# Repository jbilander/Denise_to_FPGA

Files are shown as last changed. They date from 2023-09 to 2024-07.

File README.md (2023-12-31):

# Denise_to_FPGA
A small adapter-board that connects 12-bit RGB, 14 MHz CLK, PIXELSW and SYNC-signals on Denise to a FPGA-board via a 5V-tolerant buffer.
A synchronous 14 MHz clock is generated from `C7M XOR CDAC` by using a `74LVC1G86`-chip. This will be fed into the FPGA's PLL.

Board is two layers.

WORK IN PROGRESS, NOT FULLY TESTED YET!

***

<a href="images/Denise_to_FPGA_pic1.png">
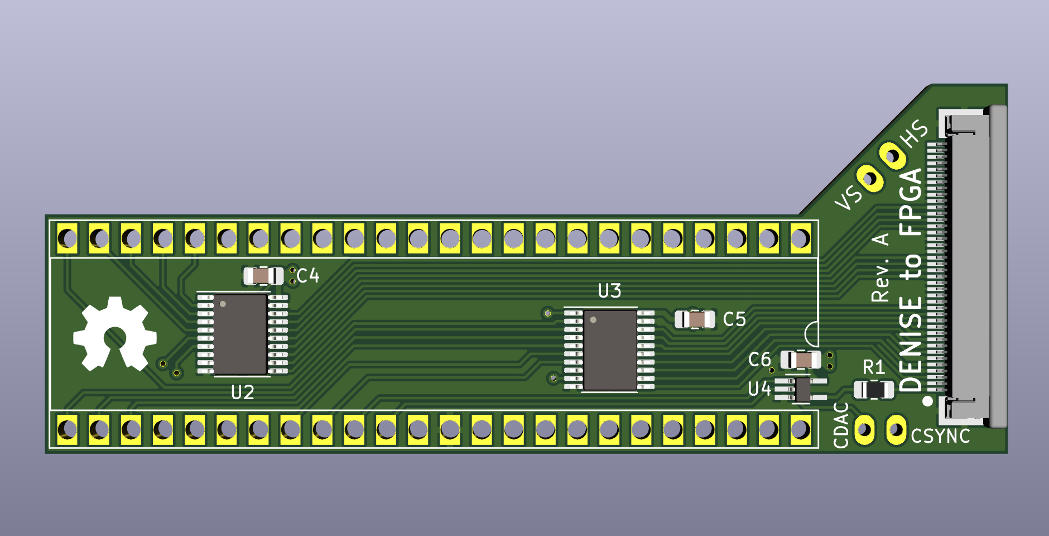
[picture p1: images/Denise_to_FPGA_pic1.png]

</a>
<a href="images/Denise_to_FPGA_pic2.png">
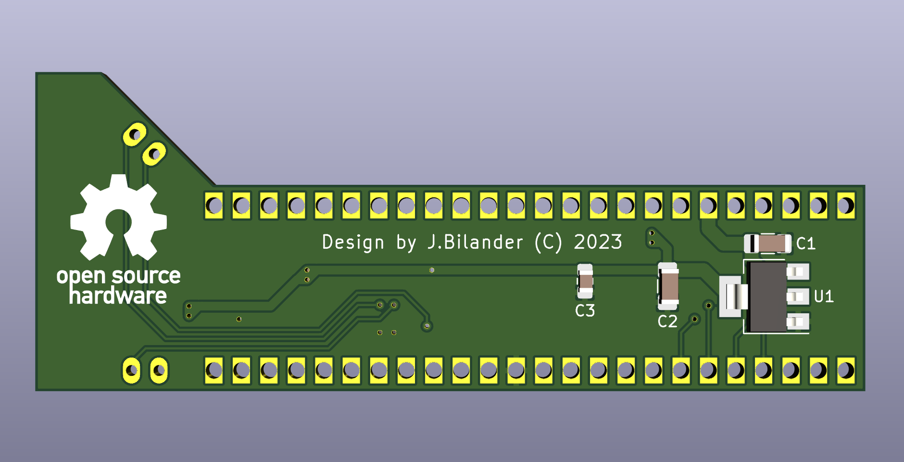
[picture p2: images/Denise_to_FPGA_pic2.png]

</a>

***
<a href="images/Denise_to_FPGA_pic3.jpg">
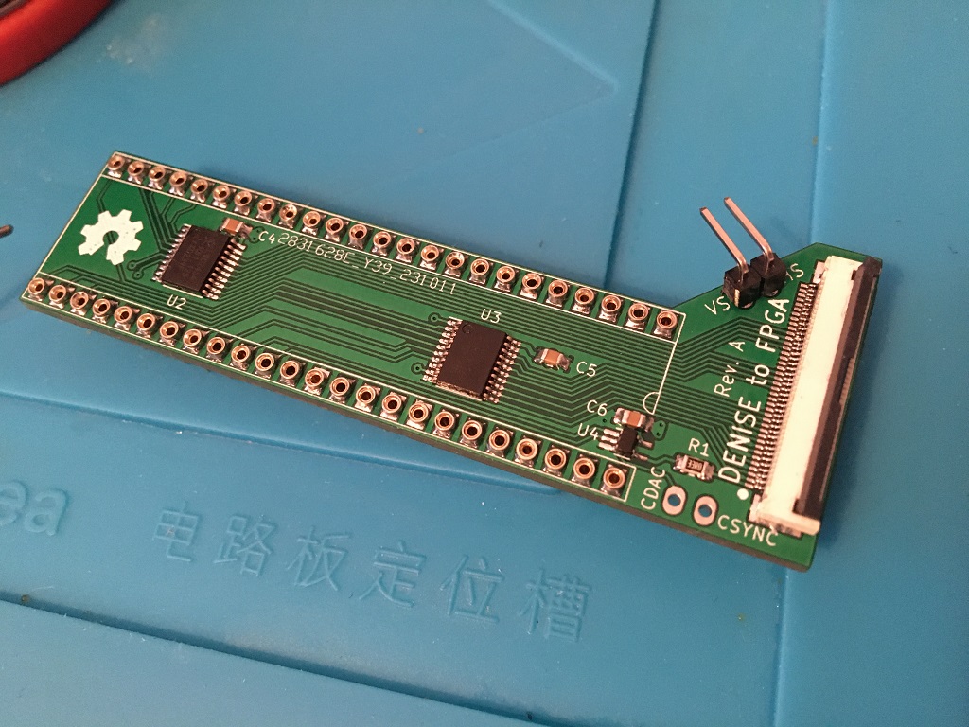
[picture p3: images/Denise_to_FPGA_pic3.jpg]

</a>
<a href="images/Denise_to_FPGA_pic4.jpg">
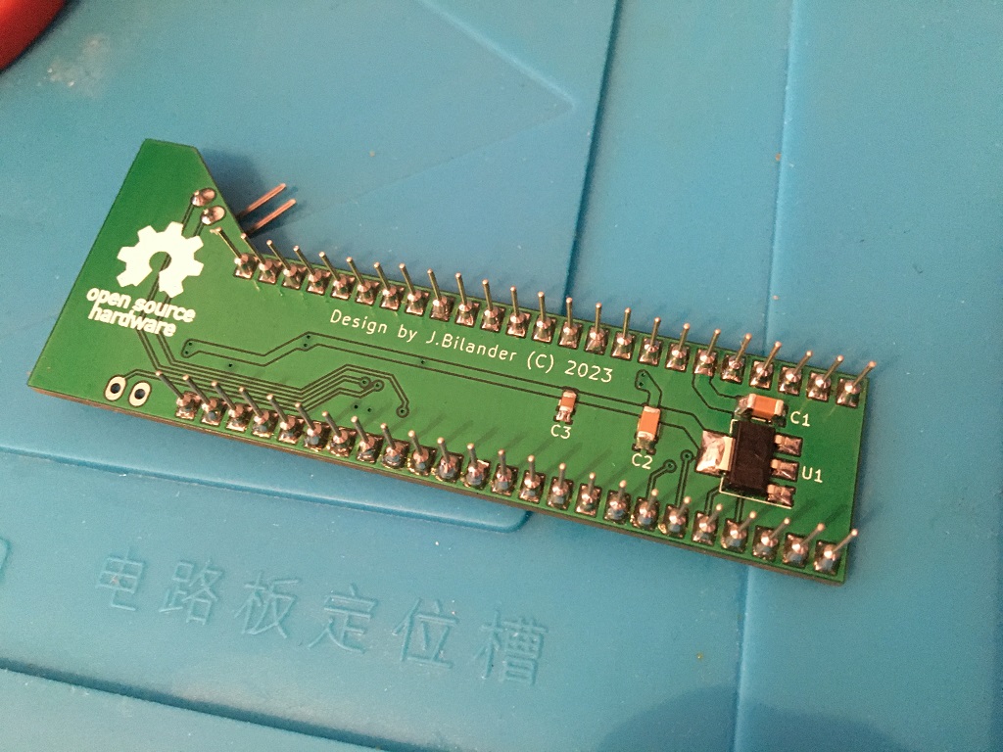
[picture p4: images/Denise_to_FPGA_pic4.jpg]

</a>
<br />
<a href="images/Denise_to_FPGA_pic5.jpg">
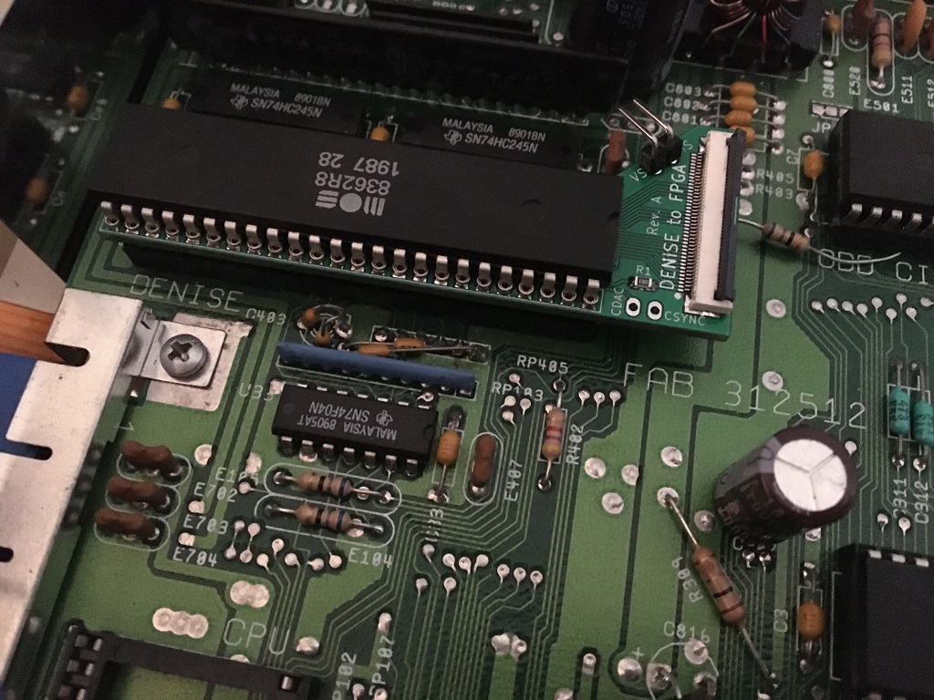
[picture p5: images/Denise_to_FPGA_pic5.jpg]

</a>
<a href="images/Denise_to_FPGA_pic6.jpg">
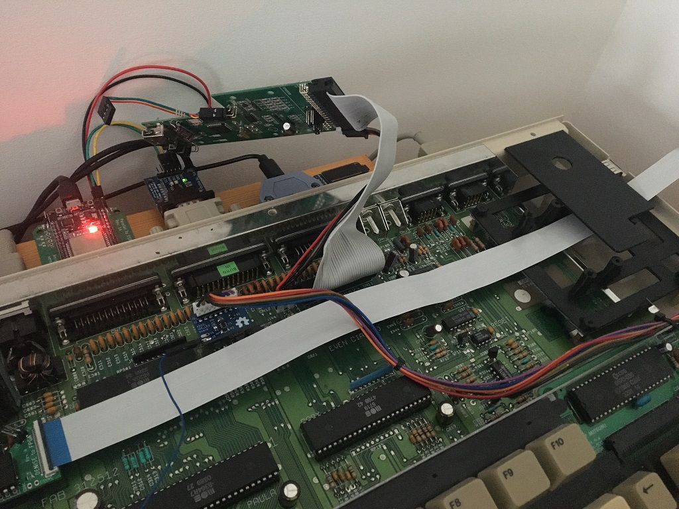
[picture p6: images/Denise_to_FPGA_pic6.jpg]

</a>

***
BOM Rev. A
---------
Designator  | Name/Value   | Package | Notes
-|-|-|-|
U1 | Voltage Regulator 3.3V, <br /> LM1117-3.3 or <br /> AMS1117-3.3 | SOT-223 | 3.3V 1A Low Drop-Out (LDO) [Voltage regulator](https://www.aliexpress.com/item/32869037691.html).
U2,U3 | Bus Transceiver 74LVC245A  | TSSOP-20 | [74LVC245APW-T](https://www.mouser.com/ProductDetail/771-74LVC245APW-T)
U4 | XOR Gate 74LVC1G86 | SOT-353 | [74LVC1G86](https://www.mouser.com/ProductDetail/621-74LVC1G86QSE-7)
U5 | 48 pcs TH socket pins | 100 Pcs | IC Leads Receptacle, Length 9.7 mm gold or nickel plated.<br />[100 pcs](https://www.aliexpress.com/item/1005002830101899.html)<br />[300 pcs](https://www.aliexpress.com/item/1005004707554342.html)<br />[1000 pcs](https://www.aliexpress.com/item/32972142300.html)<br />[1000 pcs](https://www.aliexpress.com/item/32791545218.html)
C1,C2 | Capacitor 10uF | 1206 | Caps for Voltage Regulator
C3-C6 | Capacitor 0.1uF = 100nF | 0805 | Decoupling caps
R1 | 22 or 33 Ω Resistor | 0805 | 22 or 33 Ω series resistor to [avoid reflections](https://embeddeddesignblog.blogspot.com/2022/07/why-do-we-need-series-resistor-on-clock.html) on the 14 MHz CLK
J1 | CDAC/CSYNC Two-Pin Header 2.54mm pitch | 2.54mm pitch | Connect a fly-lead here for old Rev. 3 A500 Motherboard that doesn't have these signals at the Denise socket. 
J2 | VSYNC/HSYNC Two-Pin Header 2.54mm pitch | 2.54mm pitch | Connect a fly-lead here with connection to the Horizontal and Vertical sync on DB23-backside. 
J3 | FPC connector, Right Angle, bottom contact | 0.5mm pitch, 40 positions | [TE Connectivity 4-1734592-0](https://www.mouser.com/ProductDetail/571-4-1734592-0) or [40p here](https://www.aliexpress.com/item/10000000478377.html)

***

[][cc-by-sa]

This work is licensed under a
[Creative Commons Attribution-ShareAlike 4.0 International License][cc-by-sa].

[][cc-by-sa]

[cc-by-sa]: http://creativecommons.org/licenses/by-sa/4.0/
[cc-by-sa-image]: https://licensebuttons.net/l/by-sa/4.0/88x31.png
[cc-by-sa-shield]: https://img.shields.io/badge/License-CC%20BY--SA%204.0-lightgrey.svg

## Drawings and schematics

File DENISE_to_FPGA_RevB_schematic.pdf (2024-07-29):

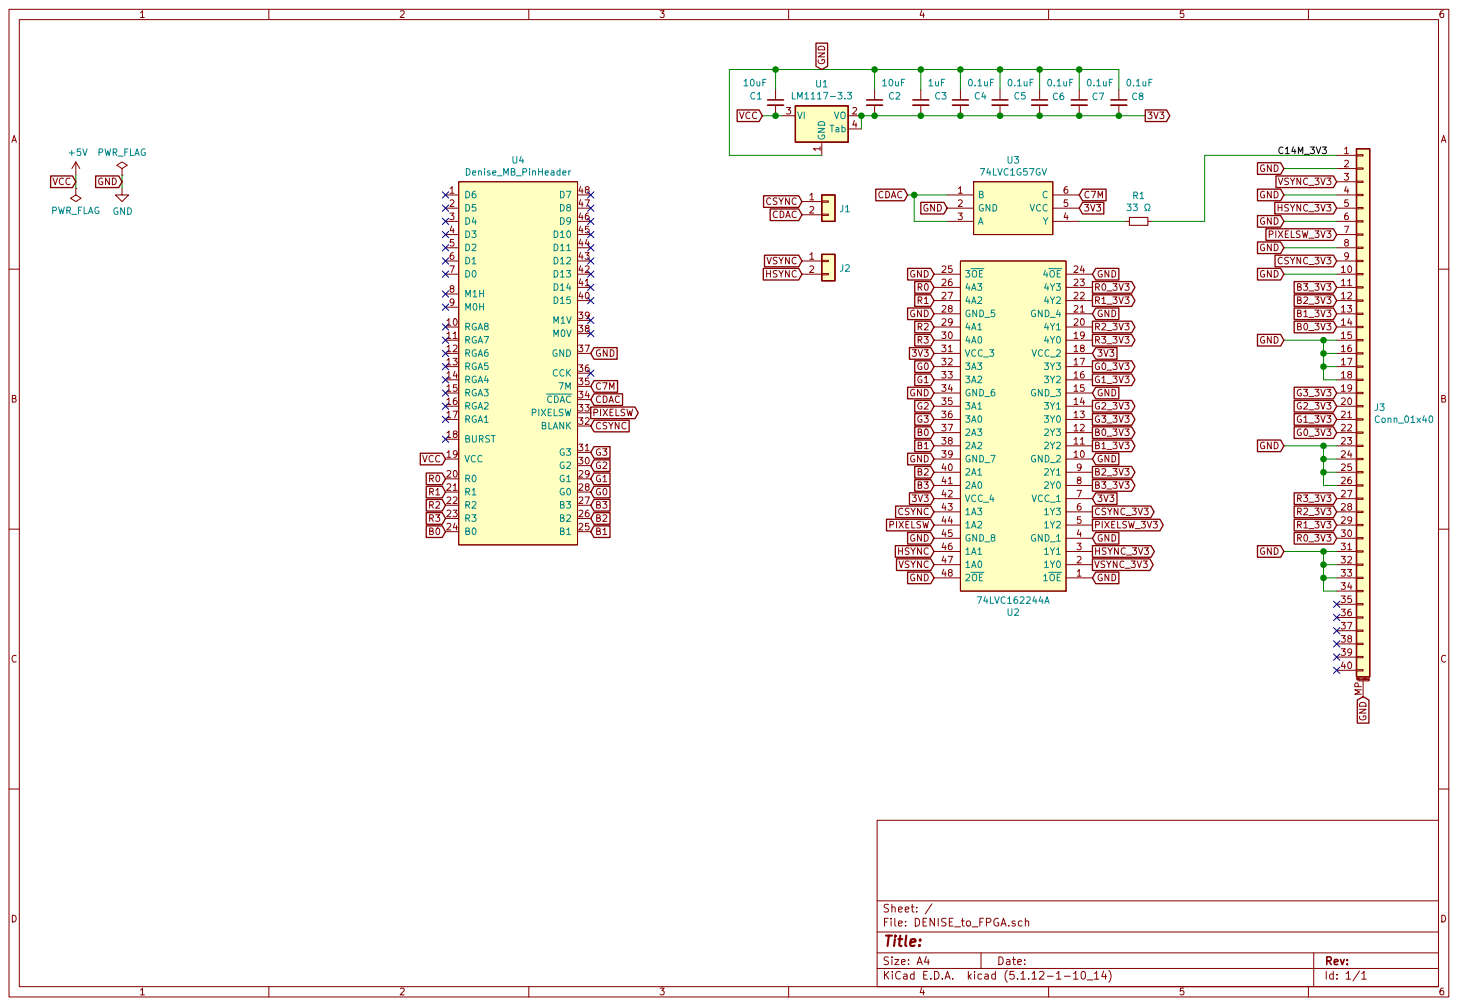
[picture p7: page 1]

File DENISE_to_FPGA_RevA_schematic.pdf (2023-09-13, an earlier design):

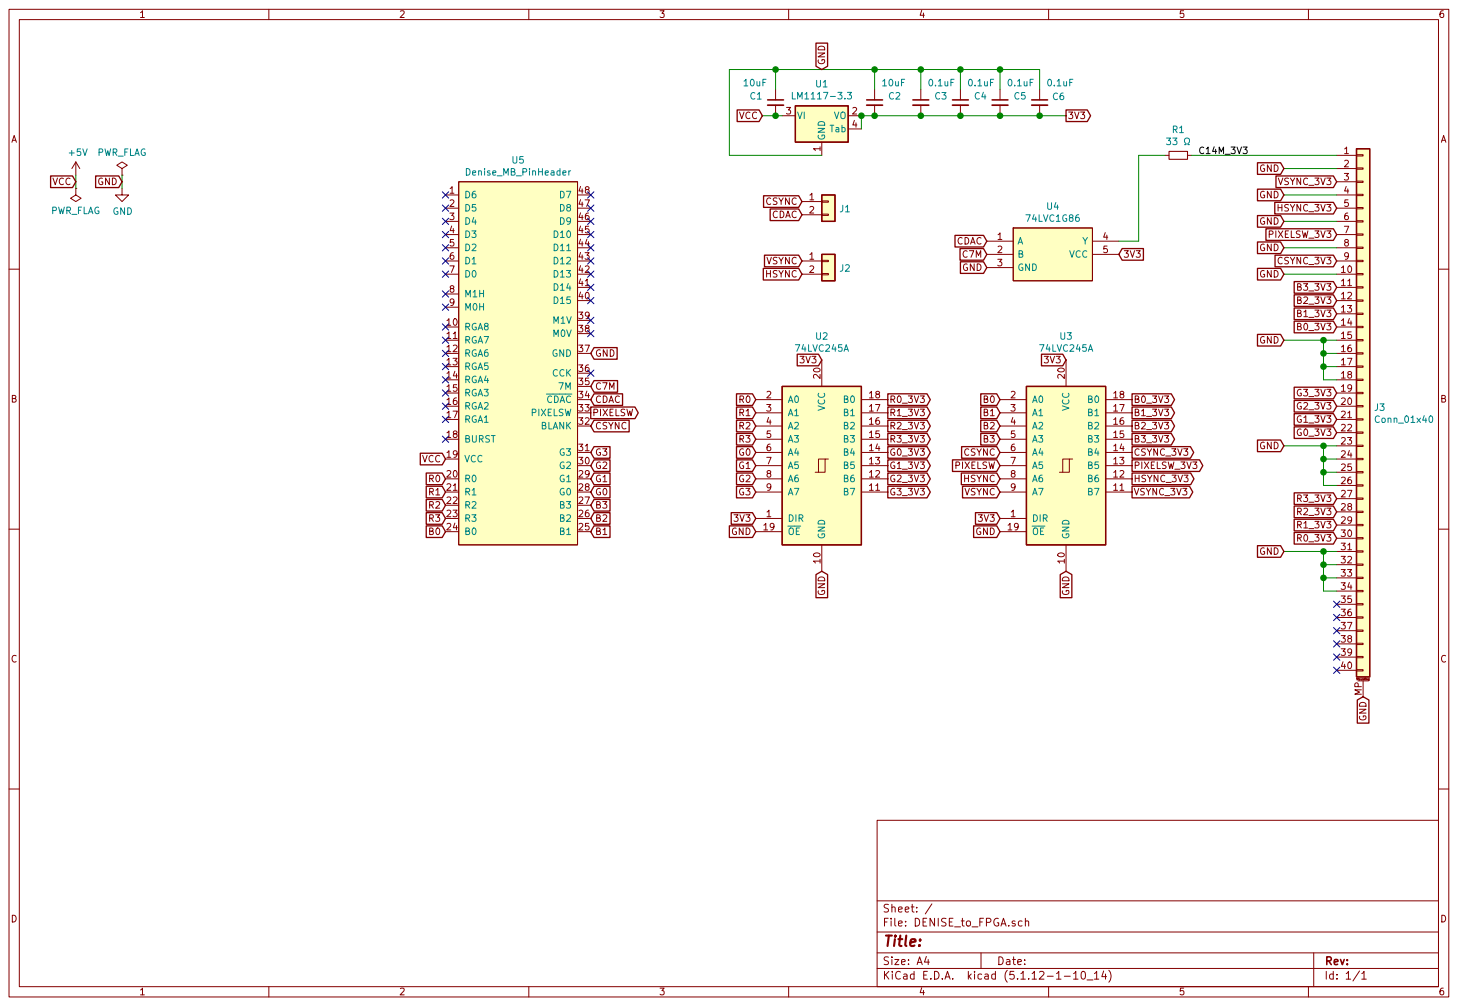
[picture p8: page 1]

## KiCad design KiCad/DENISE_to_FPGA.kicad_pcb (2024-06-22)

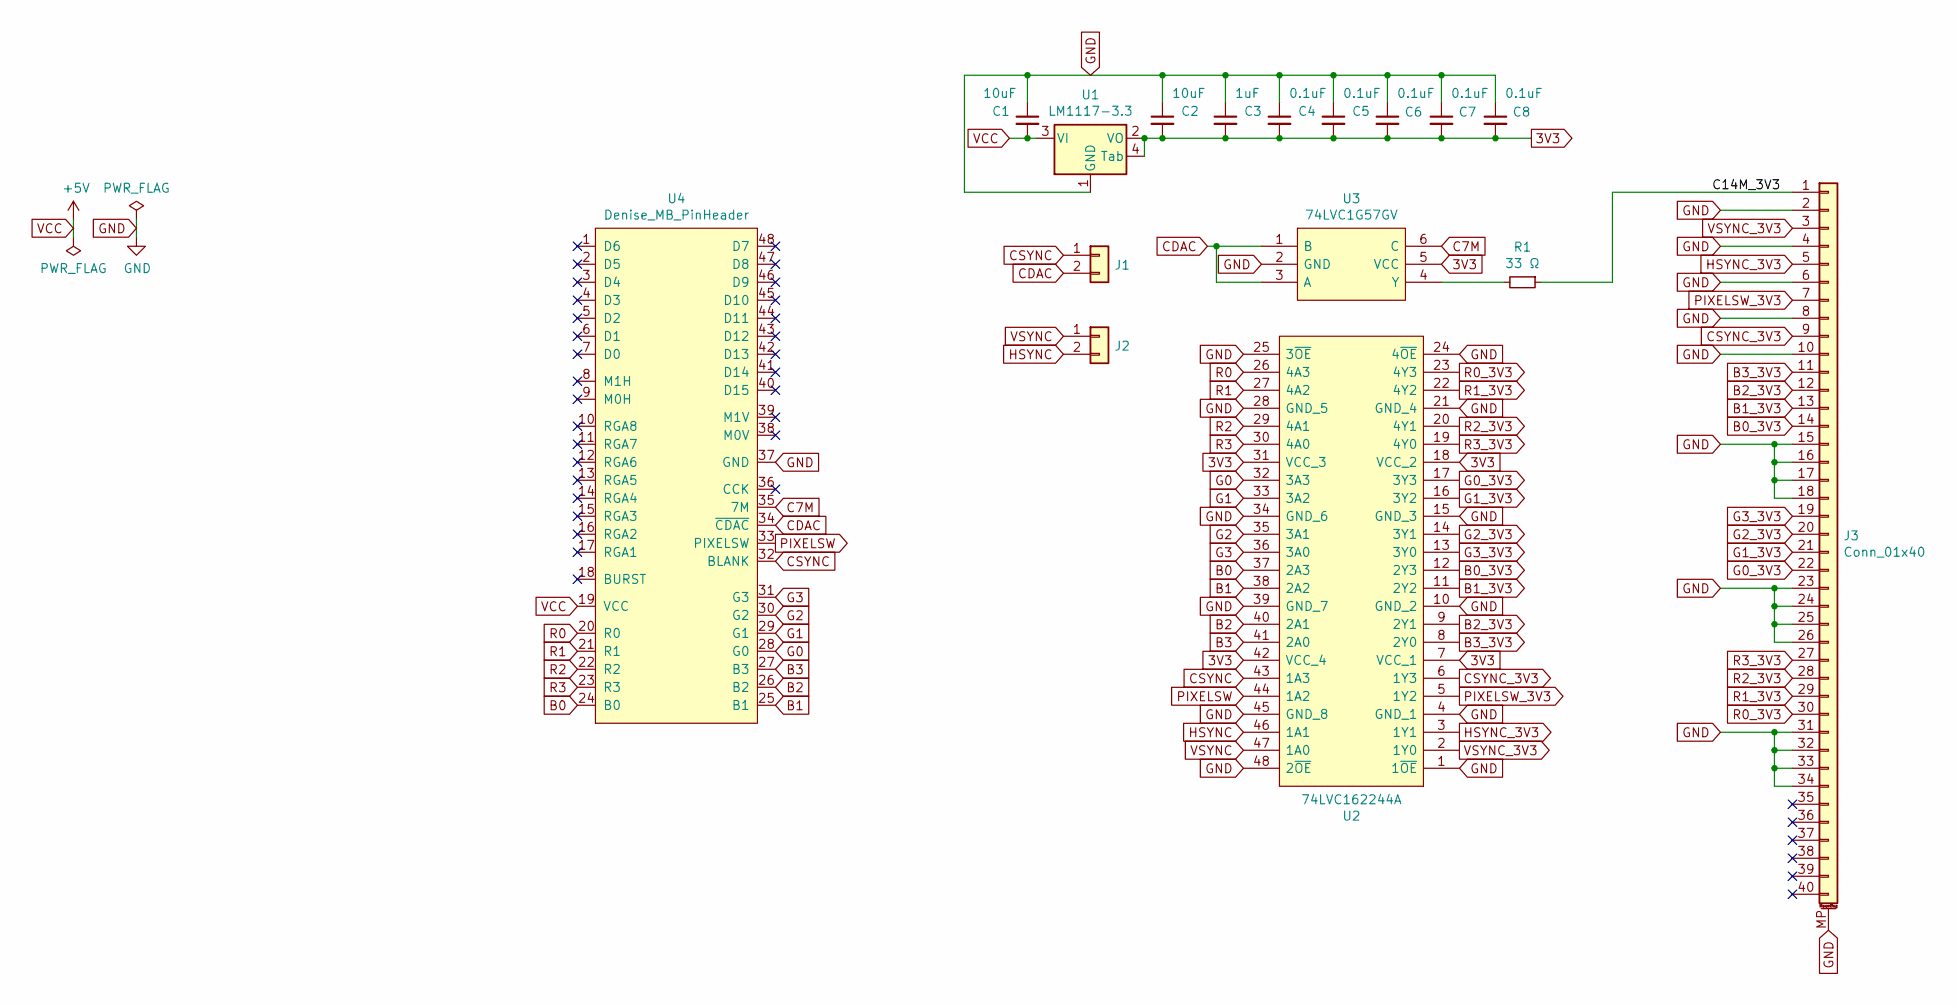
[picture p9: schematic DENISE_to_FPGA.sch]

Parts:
C1, C2: 10uF; C_1206_3216Metric_Pad1.42x1.75mm_HandSolder
C3: 1uF; C_0805_2012Metric_Pad1.15x1.40mm_HandSolder
C4, C5, C6, C7, C8: 0.1uF; C_0805_2012Metric_Pad1.15x1.4mm_HandSolder
J1, J2: Conn_01x02; PinHeader_1x02_P2.54mm_Horizontal
J3: Conn_01x40; Hirose_FH12-40S-0.5SH_1x40-1MP_P0.50mm_Horizontal
R1: 33 Ω; R_0805_2012Metric_Pad1.20x1.40mm_HandSolder
U1: LM1117-3.3; SOT-223
U2: 74LVC162244A; TSSOP-48_6.1x12.5mm_P0.5mm
U3: 74LVC1G57GV; TSOP-6_1.65x3.05mm_P0.95mm
U4: Denise_MB_PinHeader; DIP-48_W15.24mm_Socket_LongPads

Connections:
3V3: C2.2, C3.2, C4.2, C5.2, C6.2, C7.2, C8.2, U1.2 (VO), U1.4 (Tab), U2.7 (VCC_1), U2.18 (VCC_2), U2.31 (VCC_3), U2.42 (VCC_4), U3.5 (VCC)
/C14M_3V3: J3.1, R1.1
B0: U2.37 (2A3), U4.24 (B0)
B0_3V3: J3.14, U2.12 (2Y3)
B1: U2.38 (2A2), U4.25 (B1)
B1_3V3: J3.13, U2.11 (2Y2)
B2: U2.40 (2A1), U4.26 (B2)
B2_3V3: J3.12, U2.9 (2Y1)
B3: U2.41 (2A0), U4.27 (B3)
B3_3V3: J3.11, U2.8 (2Y0)
C7M: U3.6 (C), U4.35 (7M)
CDAC: J1.2, U3.1 (B), U3.3 (A), U4.34 (~CDAC)
CSYNC: J1.1, U2.43 (1A3), U4.32 (BLANK)
CSYNC_3V3: J3.9, U2.6 (1Y3)
G0: U2.32 (3A3), U4.28 (G0)
G0_3V3: J3.22, U2.17 (3Y3)
G1: U2.33 (3A2), U4.29 (G1)
G1_3V3: J3.21, U2.16 (3Y2)
G2: U2.35 (3A1), U4.30 (G2)
G2_3V3: J3.20, U2.14 (3Y1)
G3: U2.36 (3A0), U4.31 (G3)
G3_3V3: J3.19, U2.13 (3Y0)
GND: C1.1, C2.1, C3.1, C4.1, C5.1, C6.1, C7.1, C8.1, J3.2, J3.4, J3.6, J3.8, J3.10, J3.15, J3.16, J3.17, J3.18, J3.23, J3.24, J3.25, J3.26, J3.31, J3.32, J3.33, J3.34, J3.MP (MountPin), U1.1 (GND), U2.1 (1~OE), U2.4 (GND_1), U2.10 (GND_2), U2.15 (GND_3), U2.21 (GND_4), U2.24 (4~OE), U2.25 (3~OE), U2.28 (GND_5), U2.34 (GND_6), U2.39 (GND_7), U2.45 (GND_8), U2.48 (2~OE), U3.2 (GND), U4.37 (GND)
HSYNC: J2.2, U2.46 (1A1)
HSYNC_3V3: J3.5, U2.3 (1Y1)
unnamed: R1.2, U3.4 (Y)
PIXELSW: U2.44 (1A2), U4.33 (PIXELSW)
PIXELSW_3V3: J3.7, U2.5 (1Y2)
R0: U2.26 (4A3), U4.20 (R0)
R0_3V3: J3.30, U2.23 (4Y3)
R1: U2.27 (4A2), U4.21 (R1)
R1_3V3: J3.29, U2.22 (4Y2)
R2: U2.29 (4A1), U4.22 (R2)
R2_3V3: J3.28, U2.20 (4Y1)
R3: U2.30 (4A0), U4.23 (R3)
R3_3V3: J3.27, U2.19 (4Y0)
VCC: C1.2, U1.3 (VI), U4.19 (VCC)
VSYNC: J2.1, U2.47 (1A0)
VSYNC_3V3: J3.3, U2.2 (1Y0)

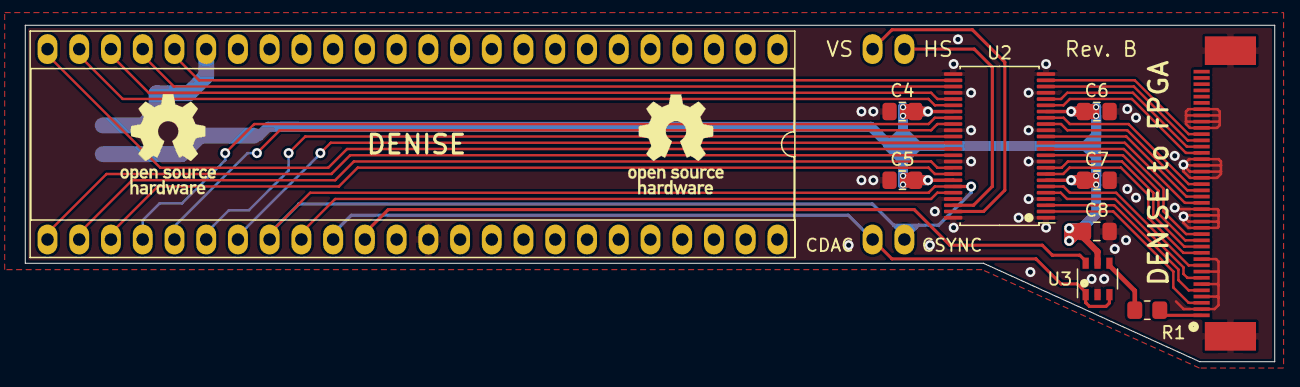
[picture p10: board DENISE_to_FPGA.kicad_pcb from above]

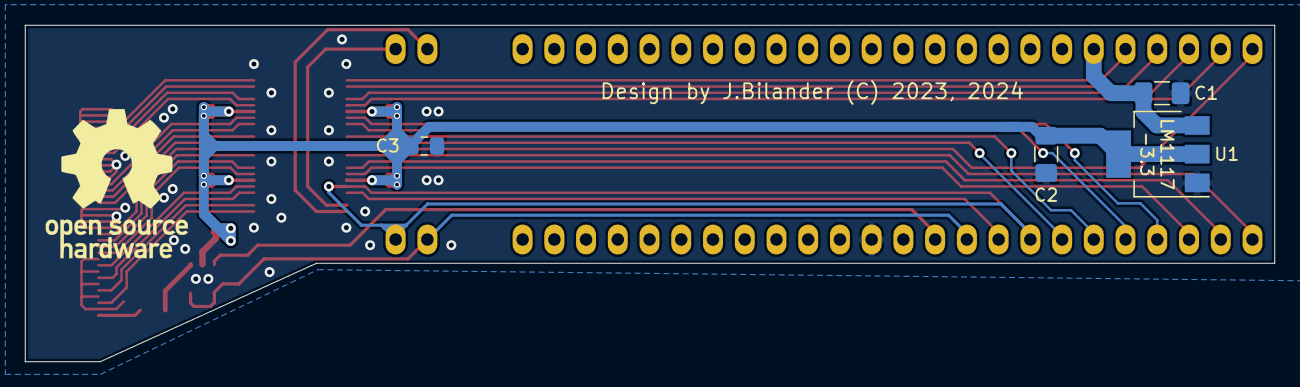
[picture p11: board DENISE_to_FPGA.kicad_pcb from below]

Board: 2 copper layers, 100.0 x 26.9 mm, 16 parts (4 on the bottom side), 39 nets.

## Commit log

2023-08-19 Added KiCAD files
    [DENISE_to_FPGA.kicad_pcb, DENISE_to_FPGA.sch]
2023-08-20 Added footprint
2023-08-20 New design, more routing done
    [DENISE_to_FPGA.kicad_pcb, DENISE_to_FPGA.sch]
2023-08-21 Fixed GND-routing on FPC-conn
    [DENISE_to_FPGA.kicad_pcb]
2023-08-21 Fixed path to footprint directory
    [DENISE_to_FPGA.kicad_pcb]
2023-09-06 Added a 74LVC1G86 XOR gate and modified the 40-pin FPC to also take a TE Connectivity 4-1734592-0, and added Hsync,Vsync-header
    [DENISE_to_FPGA.kicad_pcb, DENISE_to_FPGA.sch]
2023-09-07 Added a series resistor for C14M and changed some pin-assignments on the 40-pin FPC
    [DENISE_to_FPGA.kicad_pcb, DENISE_to_FPGA.sch]
2023-09-07 changed pin assignments on the 40-pin FPC
    [DENISE_to_FPGA.kicad_pcb, DENISE_to_FPGA.sch]
2023-09-07 Removed unused nets, added no-connect flags
    [DENISE_to_FPGA.kicad_pcb, DENISE_to_FPGA.sch]
2023-09-11 small adjustment of board length
    [DENISE_to_FPGA.kicad_pcb]
2023-09-13 small silkscreen fix
    [DENISE_to_FPGA.kicad_pcb]
2023-09-13 Added schematic pdf
2024-06-19 Updated design with a 74LVC162244ADGG, changed PCB size and TH-pins
    [DENISE_to_FPGA.kicad_pcb, DENISE_to_FPGA.sch]
2024-06-20 changed U3 from 74LVC1G86 (XOR-gate, TSSOP-5) to 74LVC1G57GV (XNOR-gate, TSOP-6)
    [DENISE_to_FPGA.kicad_pcb, DENISE_to_FPGA.sch]
2024-06-20 silkscreen fix adding dots indicating pin 1 on U2 and U3
    [DENISE_to_FPGA.kicad_pcb]
2024-06-20 Fixed orientation of U2
    [DENISE_to_FPGA.kicad_pcb, DENISE_to_FPGA.sch]
2024-06-22 silkscreen fix U2
    [DENISE_to_FPGA.kicad_pcb]
2024-07-29 Add schematic pdf
2026-11-07 Resize bord to 97 mm in length and change the shape somewhat in order to house a RP2354B chip on the underside of the board
2026-11-07 Remove PIXELSW,HSYNC,VSYNC signals and re-route CDAC,CSYNC,C7M on top side of board
2026-11-07 Add 330 Ohm resistor packs (RN1,RN2) for the RGA-signals
2026-11-08 Add footprints
2026-11-09 Update with 0.6/0.3 mm via and 0.2 mm track width
2026-11-09 Set clearance 0.1524 mm (6 mil)
2026-11-10 Add 330 Ohm series resistor on the CCK signal going to GPIO24 on the RP2354B
2026-11-11 Add resistor for C14M to XIN-pin (pin 30) on RP2354B and route track
2026-11-11 Place decoupling cap C3 near power pin 76 on RP2354B, and some silkscreen fixes
2026-11-11 Changed C1 to 1uF and size 0805 in order to fit properly inside all kind of Denise sockets
2026-11-11 Changed J1-footprint to circular 0.8 mm holes with 1.6 mm circular pads instead of oval
2026-11-12 Add a USB_B_Micro connector to the design
2026-11-12 Add 27 Ohm resistors on the USB_DP and USB_DM lines
2026-11-12 Change C3 to size 0603 and value 0.1uF, change C1 to value 1uF, change C8 to size 0603, place C3,C8,R4,R5 and route power supply and signal tracks, route power from C5 to pin 42 on U2
2026-11-13 Add 3.3V supply via 33 Ohm resistor for VREG_AVDD and a 4.7uF 1206 capacitor as decoupling.
2026-11-14 Route trace for R5 and change C references to sort ascending by size and value.

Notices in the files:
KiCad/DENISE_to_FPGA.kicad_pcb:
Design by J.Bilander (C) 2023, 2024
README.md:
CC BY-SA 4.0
